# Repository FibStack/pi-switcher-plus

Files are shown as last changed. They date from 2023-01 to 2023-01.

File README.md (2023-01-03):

# PiSwitcher Plus

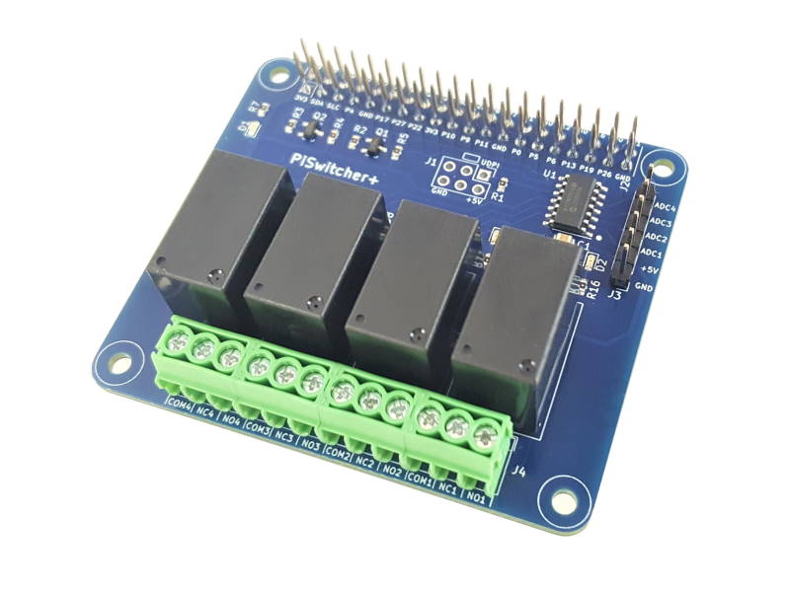
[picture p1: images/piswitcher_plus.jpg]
PiSwitcher Plus


## Overview

The **FibStack PiSwitcher Plus** board was designed to help you in your next automation project. 

The board has four high-quality relays allowing it to switch high voltage and currents. Controlling a steam iron or an oven is not the right task for the board, but it will handle most home appliances below 1200W. Each relay has an LED indicator showing when the NO (Normal Open) contact is connected to the COM (Common).

Additionally, the board has four 12-bit ADC channels that can convert electric signals up to 5 volts. The converted value allows more flexibility in the automation decision logic.

The FibStack Dashboard allows testing things on the fly without writing any code. Alternatively, you can control the board using the CLI tool or programmatically using provided libraries.
See the [Documentation](#documentation) section below for links to Getting Started guide and references.

## WARNING
**WARNING. Hazard of severe electrical shock or burn when using High Voltage/Current applications. Obey High Voltage/Current safety procedures. FibStack is not responsible for any damage or injury that occurs from improper High Voltage use.**

## Architecture

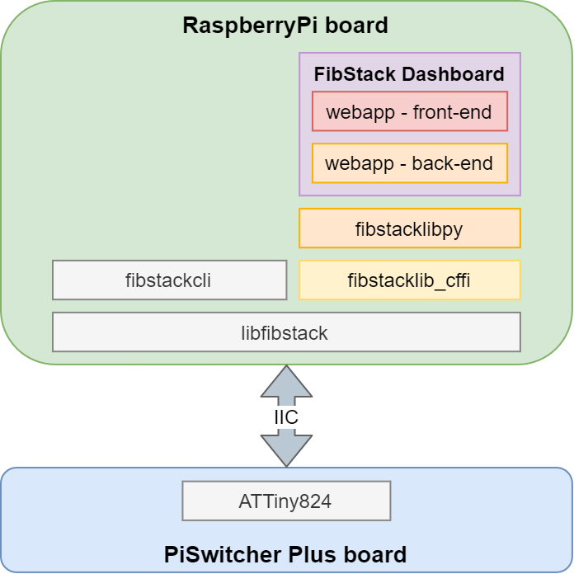
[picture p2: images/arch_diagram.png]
PiSwitcher Plus Architecture Diagram


On the PiSwitcher Plus board, the ATTiny824 microcontroller receives commands from the RaspberryPi board through the I2C interface. 
The software package facilitates communication between the Raspberry Pi and the PiSwitcher Plus board. 

The `libfibstack` library is used by any library or tool directly or indirectly.
You can use the `libfistack` library directly in your C project. Please consult the [C API Reference](https://fibstack.com/piswitcher/c_api_ref/).

The `fibstackcli` is a convenient tool to get device statuses and switch relays from the command lines.

The `fibstacklib_cffi` is a Python wrapper around the `libfistack` library. We provide a `fibstacklibpy` library for convenience if you want to use it in your Python projects. See the [Python API Reference](https://fibstack.com/piswitcher/py_api_ref/).

The FibStack Dashboard is a convenient web-based UI tool that allows you to control the PiSwitcher Plus board. It consists of the back-end python script and a front-end project that uses Angular.

## Project organization

- **piswitcher_plus_board/**: this folder is a KiCAD project that contains FibStack PiSwitcher Plus board schematics and PCB layout files.
- **software/attiny824_switch_adc_board/**: This folder contains the Microchip Studio project with the source files for the ATTiny824 microcontroller. Note that the build will create the *.hex and *.eep files. Flash the ATTiny program memory with the *.hex file and the EEPROM memory with the *.eep file.
- **software/libfibstack/**: C library containing data structures and functions to communicate with the PiSwitcher Plus board.
- **software/fibstackcli/**: This folder contains the CLI tool source code.
- **software/fibstacklib_cffi/**: This folder contains the source code for the `libfibstack` library wrapper for Python.
- **software/fibstacklibpy/**: The Python library source code.
- **software/py_webapp/**: This folder contains the source code for the back-end service.
- **software/ng-webapp/**: This folder contains the source code for the FibStack Dashboard UI. The project uses Typescript and Angular framework.
- **software/installer/**: This folder contains scripts to install and uninstall the software package on the Raspberry Pi OS. The information on how to create the installation package will be added later.

## Development tools

- **[Microchip Studio 7.0](https://www.microchip.com/en-us/tools-resources/develop/microchip-studio)**: The IDE for writing and building source code for the ATTiny chip. We also use this tool to flash the chips.
- **[ATMEL-ICE](https://www.microchip.com/en-us/development-tool/ATATMEL-ICE)**: Hardware tool for flashing program and EEPROM memories.
- **[Python CFFI](https://cffi.readthedocs.io/en/latest)**: The Python wrapper library to build the `fibstacklib_cffi` project.
- **[Angular CLI 11.1.1](https://angular.io/cli)** To develop and build Angular projects.
- **Python 3.7 and up**
- Raspberry Pi OS **GCC** compiler

## BOM

| # | Components | Recommended models | Footprint | Quantity |
| --- | --- | --- | --- | --- |
| 1 | PCB | Recommended two-layer PCB board of 1.6 mm thickness | | 1 |
| 2 | U1 | ATTiny824-SSU | SOIC-14 package, 3.9x8.7mm pitch: 1.27mm | 1 |
| 3 | C1 | Any 100nF 50V SMD capacitor | 0805 (2012 metric) | 1 |
| 4 | Q1 - Q6 | 2N7002 N-channel MOSFET transistor, 60V 300mA | SOT-23-2| 6 |
| 5 | RL1 - RL4 | General purpose SPDT 5VDC relay. Recommended models J0971C, YX201-S-105D, or similar. | J0971C | 4 |
| 6 | D1 | SMD LED RED | 0603 (1608 metric) | 1 |
| 7 | D2, D3, D6, D7 | SMD LED GREEN | 0603 (1608 metric) | 4 |
| 8 | D4, D5, D8, D9 | Any general purpose SMD Diode, 75V, 200mA | MicroMELF | 4 |
| 9 | R1, R2, R3, R4, R5, R9, R10, R15, R16 | Any 10K 5% 1/4W SMD Resistor | 0603 (1608 metric) | 9 |
| 10 | R6, R7, R8, R11, R12, R13, R14, R17, R18 | Any 1K 5% 1/4W SMD Resistor | 0603 (1608 metric) | 9 |
| 11 | J1 | Extended GPIO Male Female Header, 2x20, pitch 2.54mm | 2x20 - P2.54mm | 1 |
| 12 | J2 | Optional, Male Header Connector, 2x3, pitch 2.54mm | 2x3 - P2.54mm | 1 |
| 13 | J3 | Male Header Connector, 1x6, pitch 2.54mm | 1x6 - P2.54mm | 1 |
| 14 | J4 | Screw Terminal Block 1x12, Pitch 3.5mm. Alternatively, you can use two of 1x6, three of 1x4, or four of 1x3. | 1x12 - P3.5mm | 1|

For the Extended GPIO Male Female header connector (J1), we recommend using a component as shown in the figure below. The female part has a height of 8.5mm plus two plastic pieces of 2.5mm. The female part is placed on the bottom of the board and soldered on the top of the board. The male pins should be 9.8mm or longer to allow an additional expansion board to be connected.

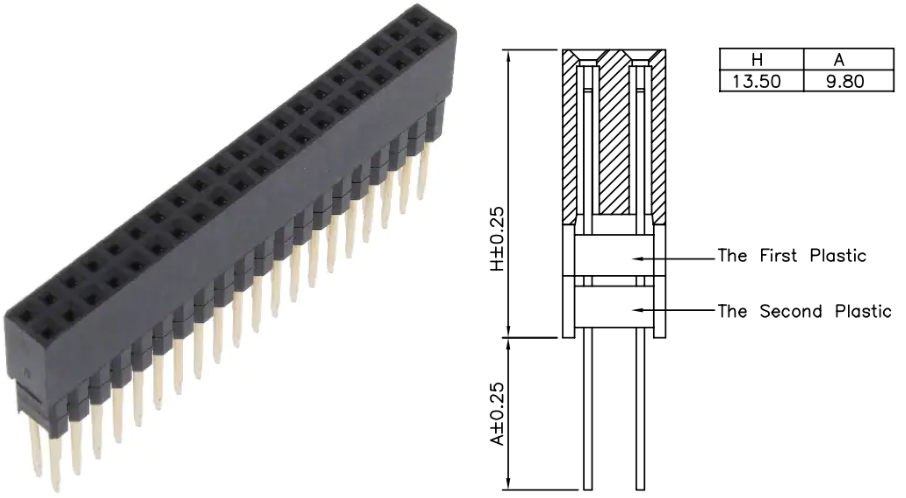
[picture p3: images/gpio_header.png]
Extended GPIO Header Connector


## Documentation
 - **[Project Home Page](https://fibstack.com/projects/piswitcher/)**
 - **[Getting Started Guide](https://fibstack.com/projects/piswitcher/get_started/)**
 - **[CLI Interface Tool](https://fibstack.com/projects/piswitcher/cli/)**
 - **[FibStack Dashboard](https://fibstack.com/projects/piswitcher/dashboard/)**
 - **[C API Reference](https://fibstack.com/projects/piswitcher/c_api_ref/)**
 - **[Python API Reference](https://fibstack.com/projects/piswitcher/py_api_ref/)**

## I2C Protocol

The software package communicates with PiSwitcher Plus through the I2C (or IIC, TWI) interface. Theoretically, you can send the instructions from any device that supports the I2C interface.
We developed a simple protocol that uses only five commands for now. 
You can write your software to control the board using the commands below.

| # | Command | Description |
| --- | --- | --- |
| 1 | `version` | Returns a constant string from the board that represents the Firmware/Hardware version. |
| 2 | `setaddr:<new_address_value>` | Set the PiSwitcher Plus board I2C address. The valid address value should be an integer between 3 and 119. |
| 3 | `status` | Returns a set of values delimited by a colon `:`. Each value represents a device value. The first four values represent the Relay values, `1 `means the relay's coil is energized, `0` otherwise. The last four values represent the values from ADC channels. Example: `0:1:1:0:120:1023:0:785`. |
| 4 | `get:<device_id>` | Returns the value (status) for the specified device. The relay devices IDs are from 0 to 3 inclusive. The ADC channel device IDs are from 4 to 7 inclusive. |
| 5 | `set:<device_id>:<value>` | Sets the value for the specified device. This command is used to switch relay devices on the PiSwitcher Plus board. The `set` command doesn't work for ADC devices as they are Read-Only. The valid values for the `device_id` are from 0 to 3 inclusive. The possible values are 0 and 1. |

## License Information
This product is open source!

Please review the LICENSE.md file for license information. Distributed as-is; no warranty is given.

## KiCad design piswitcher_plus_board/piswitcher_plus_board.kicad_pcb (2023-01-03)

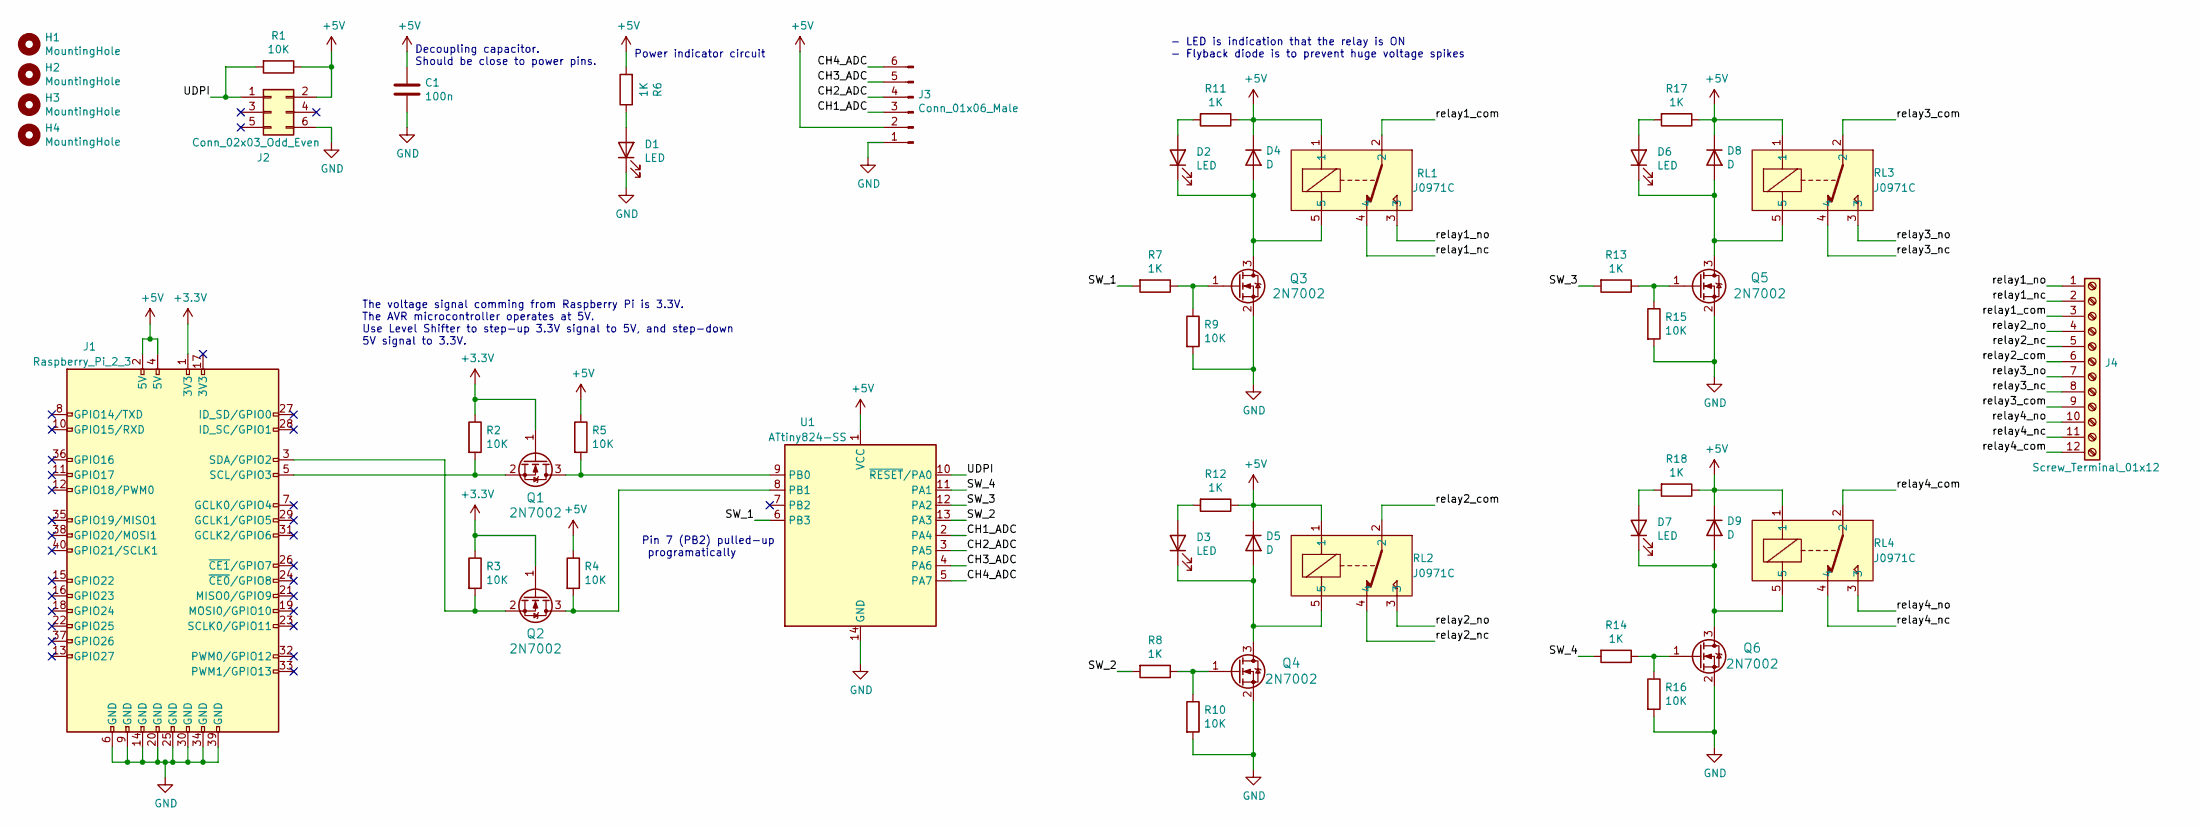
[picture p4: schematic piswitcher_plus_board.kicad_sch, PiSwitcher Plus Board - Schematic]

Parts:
C1: 100n; C_0805_2012Metric
D1, D2, D3, D6, D7: LED; LED_0603_1608Metric
D4, D5, D8, D9: D; D_MicroMELF
H1, H2, H3, H4: MountingHole; CustomMountingHole
J1: Raspberry_Pi_2_3; PinHeader_2x20_P2.54mm_Vertical
J2: Conn_02x03_Odd_Even; PinHeader_2x03_P2.54mm_Vertical
J3: Conn_01x06_Male; PinHeader_1x06_P2.54mm_Vertical
J4: Screw_Terminal_01x12; TerminalBlock_4Ucon_1x12_P3.50mm_Horizontal
Q1, Q2, Q3, Q4, Q5, Q6: 2N7002; SOT-23-3
R1, R2, R3, R4, R5, R9, R10, R15, R16: 10K; R_0603_1608Metric
R6, R7, R8, R11, R12, R13, R14, R17, R18: 1K; R_0603_1608Metric
RL1, RL2, RL3, RL4: J0971C
U1: ATtiny824-SS; SOIC-14_3.9x8.7mm_P1.27mm

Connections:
+3V3: J1.1 (3V3), Q1.1 (G), Q2.1 (G), R2.1, R3.1
+5V: C1.1, D4.1 (K), D5.1 (K), D8.1 (K), D9.1 (K), J1.2 (5V), J1.4 (5V), J2.2, J3.2, R1.1, R4.1, R5.1, R6.2, R11.1, R12.1, R17.1, R18.1, RL1.1, RL2.1, RL3.1, RL4.1, U1.1 (VCC)
/CH1_ADC: J3.3, U1.2 (PA4)
/CH2_ADC: J3.4, U1.3 (PA5)
/CH3_ADC: J3.5, U1.4 (PA6)
/CH4_ADC: J3.6, U1.5 (PA7)
/SW_1: R7.2, U1.6 (PB3)
/SW_2: R8.2, U1.13 (PA3)
/SW_3: R13.2, U1.12 (PA2)
/SW_4: R14.2, U1.11 (PA1)
/UDPI: J2.1, R1.2, U1.10 (~RESET/PA0)
/relay1_com: J4.3, RL1.2
/relay1_nc: J4.2, RL1.4
/relay1_no: J4.1, RL1.3
/relay2_com: J4.6, RL2.2
/relay2_nc: J4.5, RL2.4
/relay2_no: J4.4, RL2.3
/relay3_com: J4.9, RL3.2
/relay3_nc: J4.8, RL3.4
/relay3_no: J4.7, RL3.3
/relay4_com: J4.12, RL4.2
/relay4_nc: J4.11, RL4.4
/relay4_no: J4.10, RL4.3
GND: C1.2, D1.1 (K), J1.6 (GND), J1.9 (GND), J1.14 (GND), J1.20 (GND), J1.25 (GND), J1.30 (GND), J1.34 (GND), J1.39 (GND), J2.6, J3.1, Q3.2 (S), Q4.2 (S), Q5.2 (S), Q6.2 (S), R9.2, R10.2, R15.2, R16.2, U1.14 (GND)
unnamed: D1.2 (A), R6.1
unnamed: D2.1 (K), D4.2 (A), Q3.3 (D), RL1.5
unnamed: D2.2 (A), R11.2
unnamed: D3.1 (K), D5.2 (A), Q4.3 (D), RL2.5
unnamed: D3.2 (A), R12.2
unnamed: D6.1 (K), D8.2 (A), Q5.3 (D), RL3.5
unnamed: D6.2 (A), R17.2
unnamed: D7.1 (K), D9.2 (A), Q6.3 (D), RL4.5
unnamed: D7.2 (A), R18.2
unnamed: J1.3 (SDA/GPIO2), Q2.2 (S), R3.2
unnamed: J1.5 (SCL/GPIO3), Q1.2 (S), R2.2
unnamed: Q1.3 (D), R5.2, U1.9 (PB0)
unnamed: Q2.3 (D), R4.2, U1.8 (PB1)
unnamed: Q3.1 (G), R7.1, R9.1
unnamed: Q4.1 (G), R8.1, R10.1
unnamed: Q5.1 (G), R13.1, R15.1
unnamed: Q6.1 (G), R14.1, R16.1

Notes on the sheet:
- LED is indication that the relay is ON - Flyback diode is to prevent huge voltage spikes
Power indicator circuit
Decoupling capacitor. Should be close to power pins.
The voltage signal comming from Raspberry Pi is 3.3V. The AVR microcontroller operates at 5V. Use Level Shifter to step-up 3.3V signal to 5V, and step-down 5V signal to 3.3V.
Pin 7 (PB2) pulled-up programatically

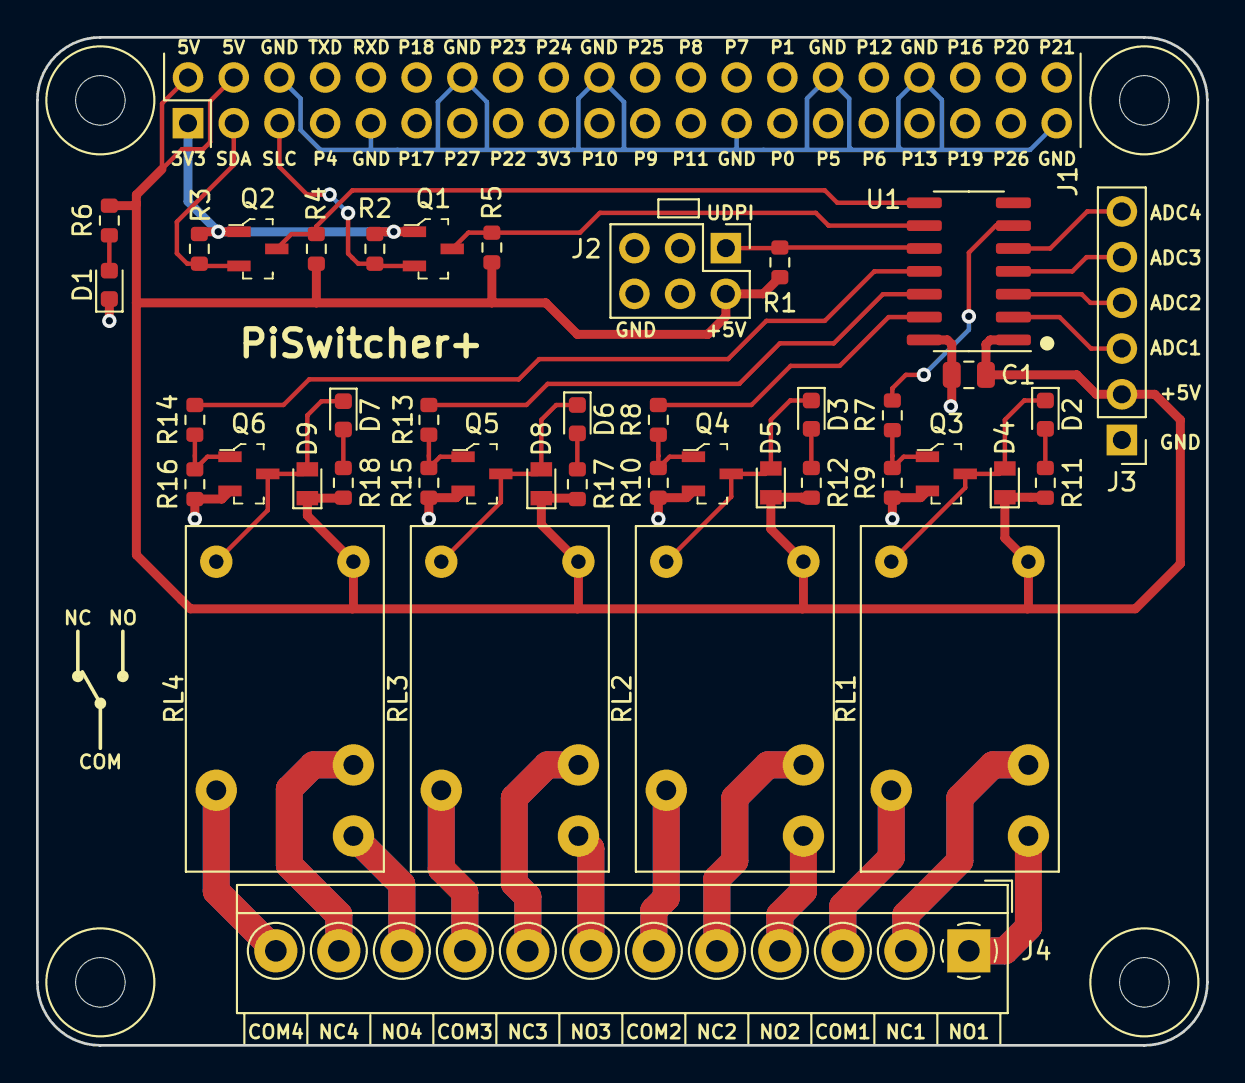
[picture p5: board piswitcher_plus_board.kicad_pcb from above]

Board: 2 copper layers, 65.0 x 56.0 mm, 47 parts (0 on the bottom side), 41 nets.

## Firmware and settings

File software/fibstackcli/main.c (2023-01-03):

/*
* Copyright (c) 2021, FibStack
* All rights reserved.
* 
* This source code is licensed under the MIT license found in the
* LICENSE file in the root directory of this source tree. 
*/
#include <stdlib.h>
#include <stdint.h>
#include <string.h>
#include <argp.h>
#include "fibstack.h"
#include "i2clib.h"


#define CURRENT_VERSION "0.9.1"

static char doc[] = "Command line utility to interact with FibStack boards.";
static char args_doc[] = "{--list-boards | -l} {--board=BOARD_INDEX | -b BOARD_INDEX |--address=ADDRESS | -a ADDRESS [--device=DEVICE_ID | -d DEVICE_ID [--set=NEW_VALUE | -s NEW_VALUE]] [--set=NEW_VALUE | -s NEW_VALUE]}";

static struct argp_option options[] = {
    {"list-boards", 'l', 0, 0, "List all the devices connected to this computer board."},
    {"board", 'b', "BOARD_INDEX", 0, "Specifies the board index. If only this parameter is specified, then it will show the status of the board."},
    {"address", 'a', "ADDRESS", 0, "Specifies the board address. If only this parameter is specified, then it will show the status of the board."},
    {"device", 'd', "DEVICE_ID", 0, "Specifies the device ID. If the set option is not specified, this will show the status of the device."},
    {"set", 's', "NEW_VALUE", 0, "Specify the new value to be assigned to the device."},
    {"version", 'v', 0, 0, "Shows the current version of the FibStack CLI tool."},
    {0}
    };

struct arguments
{
    bool list_boards;
    int board_index;
    int address;
    int device_id;
    char* value;
    bool show_version;
};

static error_t parse_arguments(int key, char *arg, struct argp_state *state)
{
    struct arguments *arguments = state->input;
    switch(key)
    {
        case 'l': arguments->list_boards = true; break;
        case 'b': arguments->board_index = arg ? atoi(arg) : -1; break;
        case 'a': arguments->address = arg ? (int) strtol(arg, NULL, 0) : -1; break;
        case 'd': arguments->device_id = arg ? atoi(arg) : -1; break;
        case 's': arguments->value = arg; break;
        case 'v': arguments->show_version = true; break;
        default:
        return ARGP_ERR_UNKNOWN;
    }
    return 0;
}

static struct argp argp = { options, parse_arguments, args_doc, doc, 0, 0, 0 };

void list_all_boards(struct fibstack_context *context);
void modify_board_address(struct fibstack_board *board, int new_address);
void get_device_info(struct fibstack_board *board, int device_id);
void set_device_value(struct fibstack_board *board, int device_id, char *value);
void show_board_info(struct fibstack_board *board);
struct fibstack_board* get_board(struct fibstack_context *context, struct arguments *arguments);

int main(int argc, char **argv)
{
    struct fibstack_context *context = fibstack_context_new();
    struct arguments arguments;
    arguments.list_boards = false;
    arguments.board_index = -1;
    arguments.address = -1;
    arguments.device_id = -1;
    arguments.value = NULL;
    arguments.show_version = false;
    
    argp_parse(&argp, argc, argv, 0, 0, &arguments);
    
    int total_boards = fibstack_context_get_board_number(context);
    bool is_board_index_valid = arguments.board_index > -1 && arguments.board_index < total_boards;
    bool is_board_address_valid = arguments.address >= I2C_ADDRESS_MIN && arguments.address < I2C_ADDRESS_MAX;
    bool invalid_board_indentifier = !(is_board_index_valid || is_board_address_valid);
    
    if(arguments.list_boards)
    {
        // LIST ALL BOARDS
        list_all_boards(context);
        invalid_board_indentifier = false;
    } 
    else if (arguments.show_version)
    {
        // SHOW CURRENT VERSION
        printf("%s\n", CURRENT_VERSION);
        invalid_board_indentifier = false;
    }
    else if(!invalid_board_indentifier)
    {
        struct fibstack_board *board = get_board(context, &arguments);

        if(!board)
        {
            invalid_board_indentifier = true;
        }
        else if(arguments.device_id > -1 && arguments.value != NULL)
        {
            // SET DEVICE VALUE
            set_device_value(board, arguments.device_id, arguments.value);
        }
        else if (arguments.device_id > -1 && arguments.value == NULL)
        {
            // GET DEVICE INFO
            get_device_info(board, arguments.device_id);
        }
        else if(arguments.device_id <= -1 && arguments.value != NULL)
        {
            // SET BOARD ADDRESS
            int new_address = (int) strtol(arguments.value, NULL, 0);
            modify_board_address(board, new_address);
        }
        else
        {
            // SHOW BOARD STATUS
            show_board_info(board);
        }
    }
    
    if(invalid_board_indentifier)
    {
        printf("ERROR: Invalid value for the [--board, -b, --address, -a] options.\n");
    }
    
    fibstack_context_free(context);
    
    return EXIT_SUCCESS;
}

/**
* Returns the pointer of the fibstack_board structure, it find the board by specified index or address.
*/
struct fibstack_board* get_board(struct fibstack_context *context, struct arguments *arguments)
{
    struct fibstack_board *board = NULL;
    if(arguments)
    {
        if(arguments->board_index > -1)
        {
            board = fibstack_context_get_board_by_index(context, arguments->board_index);
        }
        else if (arguments->address > -1)
        {
            board = fibstack_context_get_board_by_address(context, arguments->address);
        }
    }

    return board;
}

/**
 * List all the boards from the provided context
 */
void list_all_boards(struct fibstack_context *context)
{
    int total_boards = fibstack_context_get_board_number(context);
    printf("Total boards found: %d\n", total_boards);
    if(total_boards > 0)
    {
        printf(" Id   Address    Devices    Descriptions\n");
        printf("-----------------------------------------------------------\n");
    }
    for(int i = 0; i < total_boards; i++)
    {
        struct fibstack_board *board = fibstack_context_get_board_by_index(context, i);
        int i2c_address = fibstack_board_get_address(board);
        int total_devices = fibstack_board_get_device_number(board);
        char* description = fibstack_board_get_description(board);
        printf("%3d  %2d(0X%2X)    %7d    %30s\n", i, i2c_address, i2c_address, total_devices, description);
    }
}

/**
 * Modifies the I2C address of the specified board.
 * The address will not change if the provided value for the new address is invalid
 */
void modify_board_address(struct fibstack_board *board, int new_address)
{
    bool is_new_address_valid = board 
        && new_address > I2C_ADDRESS_MIN 
        && new_address < I2C_ADDRESS_MAX;
    bool is_address_available = true;
    
    // Check if the address is not taken by another board
    if(is_new_address_valid)
    {
        char *test_message = send_get_data(new_address, "version", false);
        if(strcmp(test_message, LIB_ERROR_MSG) != 0)
        {
            is_new_address_valid = false;
            is_address_available = false;
        }
    }
    
    if(is_new_address_valid)
    {
        int set_address_result = fibstack_board_set_address(board, new_address);
        if(set_address_result != new_address)
        {
            printf("ERROR: Could not set the new address\n");
        }
        else 
        {
            printf("SUCCESS: The new address was set succesfully\n");
        }
    }
    else if(!is_address_available)
    {
        printf("ERROR: Address %d is not available.\n", new_address);
    }
    else
    {
        printf("ERROR: Invalid value for the [--address, -a] option.\n");
    }
}

/**
 * Shows the information for the specified device
 */
void get_device_info(struct fibstack_board *board, int device_id)
{
    int total_devices = fibstack_board_get_device_number(board);
    bool is_device_id_valid = device_id > -1 && device_id < total_devices;
    
    if( is_device_id_valid)
    {
        enum fibstack_value_type value_type = fibstack_board_get_device_value_type(board, device_id);
        bool is_device_read_only = fibstack_board_is_device_read_only(board, device_id);
        char *device_description = fibstack_board_get_device_description(board, device_id);
        char* read_only_str = "";
        if(is_device_read_only)
        {
            read_only_str = ", Read Only";
        }
        if(value_type == BOOLEAN_TYPE)
        {
            int bool_value = fibstack_board_get_boolean(board, device_id);
            printf("%s. ID: %d, Value = %s%s\n", device_description, device_id, bool_value ? "true" : "false", read_only_str);
        }
        else if (value_type == INTEGER_TYPE)
        {
            int int_value = fibstack_board_get_integer(board, device_id);
            printf("%s. ID: %d, Value = %d%s\n", device_description, device_id, int_value, read_only_str);
        }
        else
        {
            printf("INFO: Unknown device type.\n");
        }
    }
    else
    {
        printf("ERROR: Invalid value for the [--device, -d] option.\n");
    }
    
}

/**
 * Sets the specified device with specified value if not Read Only
 */
void set_device_value(struct fibstack_board *board, int device_id, char *value)
{
    int total_devices = fibstack_board_get_device_number(board);
    bool is_device_id_valid = device_id > -1 && device_id < total_devices;
    
    if( is_device_id_valid)
    {
        bool is_device_read_only = fibstack_board_is_device_read_only(board, device_id);
        if(is_device_read_only)
        {
            printf("ERROR: Device is Read Only, cannot set.\n");
        }
        else
        {
            enum fibstack_value_type value_type = fibstack_board_get_device_value_type(board, device_id);
            if(value_type == BOOLEAN_TYPE)
            {
                // Set the value to lower case
                for(int i = 0; i < strlen(value); i++)
                {
                    value[i] = tolower(value[i]);
                }
                if(strcmp("true", value)==0 || strcmp("1", value)==0)
                {
                    // Set boolean value to TRUE
                    fibstack_board_set_boolean(board, device_id, true);
                } 
                else if(strcmp("false", value)==0 || strcmp("0", value)==0)
                {
                    // Set boolean value to FALSE
                    fibstack_board_set_boolean(board, device_id, false);
                }
                else
                {
                    printf("ERROR: Unsupported value %s\n", value);
                }
            }
            else
            {
                printf("INFO: Device type not supported.\n");
            }
        }
    }
    else
    {
        printf("ERROR: Invalid value for the [--device, -d] option.\n");
    }
}

/**
 * Shows all the infow about specified board.
 */
void show_board_info(struct fibstack_board *board)
{
    int i2c_address = fibstack_board_get_address(board);
    int total_devices = fibstack_board_get_device_number(board);
    char *description = fibstack_board_get_description(board);
    printf("I2C address %d(0X%2X)\n", i2c_address, i2c_address);
    printf("Description: %s\n", description);
    printf("Total devices: %d\n", total_devices);
    if(total_devices > 0)
    {
        printf(" ID  Value Type  Value  Read Only  Description\n");
        printf("------------------------------------------------\n");

        for(int i = 0; i < total_devices; i++)
        {
            enum fibstack_value_type value_type = fibstack_board_get_device_value_type(board, i);
            int int_value = fibstack_board_get_integer(board, i);
            int bool_value = fibstack_board_get_boolean(board, i);
            bool is_read_only = fibstack_board_is_device_read_only(board, i);
            char *device_description = fibstack_board_get_device_description(board, i);
            char *str_type;
            switch(value_type)
            {
                case BOOLEAN_TYPE: str_type = "BOOLEAN"; break;
                case INTEGER_TYPE: str_type = "INTEGER"; break;
                default: str_type = "UNKNOWN";
            }
            printf("%3d%12s%7d%11s  %s\n", i, str_type, value_type == BOOLEAN_TYPE ? bool_value : int_value, is_read_only ? "Yes" : "No", device_description);
        }
    }
}

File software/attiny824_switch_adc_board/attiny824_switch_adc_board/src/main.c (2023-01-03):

/*
* Copyright (c) 2021, FibStack
* All rights reserved.
* 
* This source code is licensed under the MIT license found in the
* LICENSE file in the root directory of this source tree. 
*/

#include <xc.h>
#include <stdlib.h>
#include <string.h>
#include <avr/interrupt.h>
#include <avr/eeprom.h>
#include "util.h"
#include "twi.h"
#include "output.h"
#include "adc.h"

#define RESPONSE_INVALID "INVALID"
#define RESPONSE_OK "OK"
#define RESPONSE_ON "1"
#define RESPONSE_OFF "0"
#define RESPONSE_ERROR "ERROR"
#define TOTAL_DEVICES 8

// The part before the "_" character identifies the hardware design version, the last four characters identifies the software version.
// First two digits for the major version, and second two digits for the minor version. 
// The micro version is not included since it should contain only bug fixes and not break the old functionality.
#define RESPONSE_VERSION "FBSWP01_0101"

uint8_t EEMEM eeprom_twi_address = 0x50;

void set_twi_address(uint8_t new_address);
void process_set_address();
void set_response(char *response);
void process_get_status();
void process_get();
void process_set();

ISR(ADC0_RESRDY_vect)
{
	ADC0_process();
}

ISR(TWI0_TWIS_vect)
{
	TWI0_process_interrupt();
}

int main(void)
{
	uint8_t twi_address = eeprom_read_byte(&eeprom_twi_address);
	TWI0_init(twi_address);
	output_init();
	ADC0_init();
	sei(); // Enable Global Interrupts
	
	ADC0_start(); // Start ADC conversion to have the data ready
	
	while(1)
	{
		// wait for interrupts
	}
}

void TWI0_process_command()
{
	if(bytes_read > 0)
	{
		char *token = strtok(read_buffer, ":");
		
		
		if(strcmp("setaddr", token) == 0)
		{
			// function: setaddr
			// Sets the board I2C address
			// Format: setaddr:<new_address_value>
			process_set_address();
		}
		else if(strcmp("version", token) == 0)
		{
			// function: version
			// Returns the device version
			// Format: version
			set_response(RESPONSE_VERSION);
		}
		else if(strcmp("status", token) == 0)
		{
			// function: status
			// Returns the data from all devices
			// Format: status
			process_get_status();
		}
		else if(strcmp("get", token) == 0)
		{
			// function: get
			// Returns the data value for the specified device
			// Format: get:<device_id>
			process_get();
		}
		else if (strcmp("set", token) == 0)
		{
			// function: set
			// Set the data for the specified device
			// Format: set:<device_id>:<value>
			process_set();
		}
		else
		{
			set_response(RESPONSE_INVALID);
		}
	}
	
}

void process_set_address()
{
	char *param_token = strtok(NULL, ":");
	short param = str2pos_num(param_token);
	if(param > 2 && param < 120) {
		set_twi_address((uint8_t)param);
		// Clear the buffer, address was changed.
		memset(write_buffer, '\0', TWI_BUFFER_SIZE);
	}
	else
	{
		set_response(RESPONSE_INVALID);
	}
}

void set_response(char *response)
{
	memset(write_buffer, '\0', TWI_BUFFER_SIZE); // clear the buffer
	strcpy(write_buffer, response); // set new text
}

void set_twi_address(uint8_t twi_address)
{
	cli();
	eeprom_update_byte(&eeprom_twi_address, twi_address);
	TWI0_set_address(twi_address);
	sei();
	ADC0_start(); // Start the ADC again
}

void process_get_status()
{
	uint8_t i;
	uint8_t length = 0;
	memset(write_buffer, '\0', TWI_BUFFER_SIZE); // clear the buffer
	
	// Get output devices status
	for(i = 0; i < OUTPUT_DEVICES; i++)
	{
		uint8_t result = output_get(i);
		if(result > 0)
		{
			result = 1;
		}
		write_buffer[length] = '0' + result;
		write_buffer[length + 1] = ':';
		length += 2;
	}

	// Get ADC devices status
	for(i = 0; i < ADC_CHANNELS; i++)
	{
		char *adc_value = num2str(adc_result[i]);
		uint8_t adc_value_len = strlen(adc_value);
		uint8_t j;
		for(j = 0; j < adc_value_len; j++)
		{
			write_buffer[length] = adc_value[j];
			length++;
		}
		if(i < ADC_CHANNELS - 1)
		{
			write_buffer[length] = ':';
			length++;
		}
		free(adc_value);
	}
}

void process_get()
{
	char *device_id_token = strtok(NULL, ":");
	short device_id = str2pos_num(device_id_token);
	
	
	if(device_id > -1 && device_id < TOTAL_DEVICES)
	{
		if(device_id < OUTPUT_DEVICES)
		{
			// Get Relay Switch status
			uint8_t result = output_get(device_id);
			if(result == 0)
			{
				set_response(RESPONSE_OFF);
			}
			else if (result == output_devices[device_id][1])
			{
				set_response(RESPONSE_ON);
			}
			else
			{
				set_response(RESPONSE_ERROR);
			}
		}
		else
		{
			// Get ADC value
			char *adc_value = num2str(adc_result[ADC_CHANNELS - device_id]);
			set_response(adc_value);
			// This memory space is not managed, clean it up
			free(adc_value);
		}
	}
	else
	{
		set_response(RESPONSE_INVALID);
	}
}

void process_set()
{
	char *device_id_token = strtok(NULL, ":");
	char *value_token = strtok(NULL, ":");
	short device_id = str2pos_num(device_id_token);
	short value = str2pos_num(value_token);
	
	if(device_id > -1 && device_id < OUTPUT_DEVICES && (value == 0 || value == 1))
	{
		if(output_set(device_id, value) == 0)
		{
			set_response(RESPONSE_OK);
		}
		else
		{
			set_response(RESPONSE_ERROR);
		}
	}
	else
	{
		set_response(RESPONSE_INVALID);
	}
}

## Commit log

2022-10-14 Initial commit with the files from old repo
    [relays_adcs_board_hardware.kicad_pcb, relays_adcs_board_hardware.sch]
2022-10-16 Converted the kicad5 project to kicad6 project
    [piswitcher_plus_board.kicad_pcb, piswitcher_plus_board.kicad_sch, relays_adcs_board_hardware.kicad_pcb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]
2022-10-16 Fixed more sonar issues
2022-10-16 Fixed sonar issue
2023-01-03 Merging most updated code to master (#3)
    * Initial commit with the files from old repo
    * Converted the kicad5 project to kicad6 project
    * Initial code clean up
    * Ng update performed
    * Minor sonnar issue fixes
    * Fixed more sonar issues
    * Fixed sonar issue
    * Updated header files
    * Wrote the README.md, LICENSE.md, and other modifications
    * Minor changes to the README
    * Updated text from Fibstack to FibStack, updated readme
    * Added the image
    * Jenkins pipeline file (#1)
    Created Jenkinsfile to streamline the installation package build.
    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
    [piswitcher_plus_board.kicad_pcb, piswitcher_plus_board.kicad_sch]

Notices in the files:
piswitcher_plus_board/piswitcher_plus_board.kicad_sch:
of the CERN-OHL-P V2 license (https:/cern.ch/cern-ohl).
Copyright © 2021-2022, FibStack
